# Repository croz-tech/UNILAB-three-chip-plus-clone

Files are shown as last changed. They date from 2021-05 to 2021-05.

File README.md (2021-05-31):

# UNILAB three-chip-plus-clone
**A clone of the main UNILAB 6502 learning board, part number 540.300**<BR><BR>
Features & changes over the [original UNILAB educational system](http://retro.hansotten.nl/6502-sbc/three-chips-plus/):
- Compatible with 6502/6522 or newer 65C02/65C22 fully static parts
- 1Mhz crystal replaced with oscillator module (more readily available)
- Internal/external clock selectable by jumper
- Address bus, Data bus, R/W and Clock available on headers to be compatible with [Ben Eater](https://eater.net/6502)'s [Arduino Mega Moitor](https://eater.net/downloads/6502-monitor.ino)
- Compatible with original three-chip-plus I/O peripheral boards, Program Memory Board, and Program Loader
- Original PCB form factor (yes, rather large by today's standards but I went for originality
- **See note at bottom of this page for ISS1 (ONLY ISS1) board error and modification**

## Assembled PCB (ISS1):


## Schematic (ISS2):


## ERROR and correction for ISS1 schematic and PCB
Note: there are two errors on the ISS1 **ONLY** schematic and boards, these are fixed on ISS2 in the design:
1) Polarity of POWER IN is reversed on the PCB legend (but correctly diode-protected)
2) Clock error, where U4 (the 6522 pin 25) should be driven with PHI2 (same phase as U5, the 6502) and U2 pins 2,10,12 should be driven with ~PHI2 (inverted phase compared to the 6502 and 6522).  Correcting this involves two track breaks and two wires being fitted to the PCB as below (one on the component-side below the socket of U3, one on the solder-side):
Modification 1
Modification 2

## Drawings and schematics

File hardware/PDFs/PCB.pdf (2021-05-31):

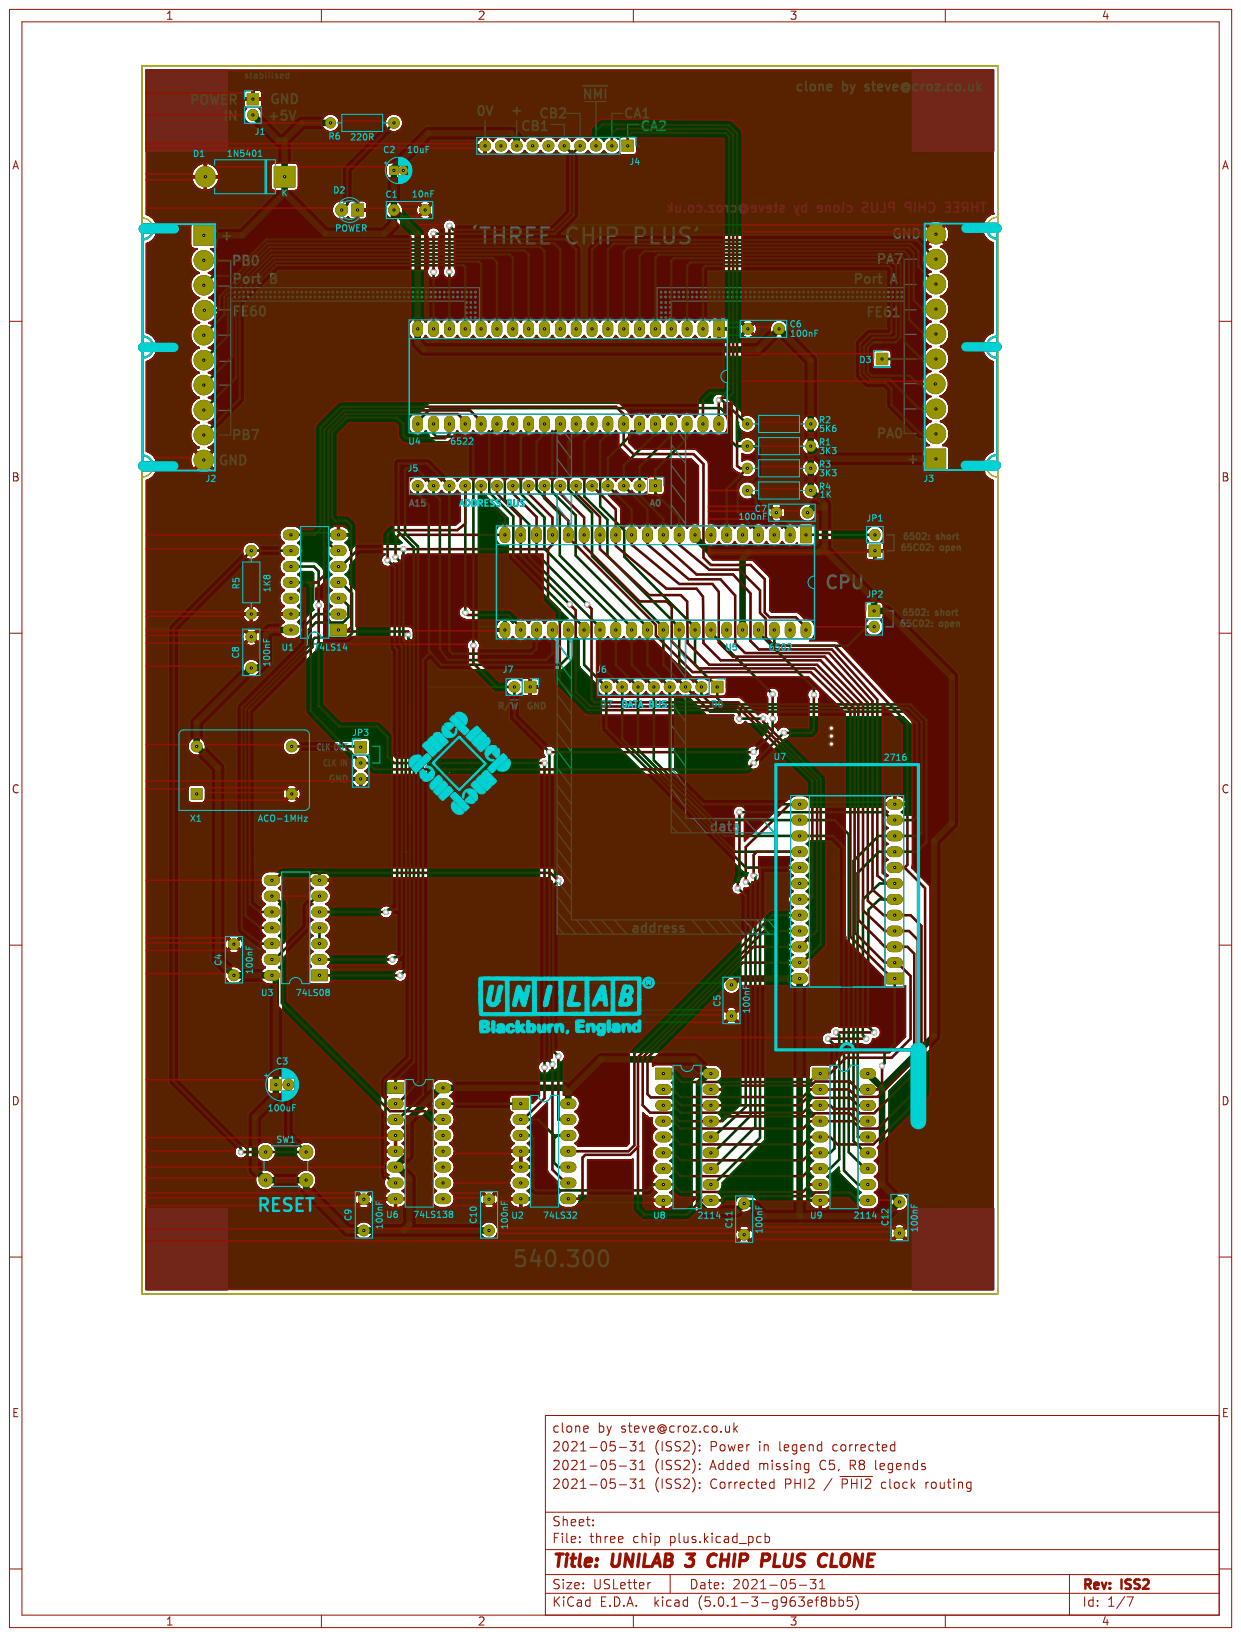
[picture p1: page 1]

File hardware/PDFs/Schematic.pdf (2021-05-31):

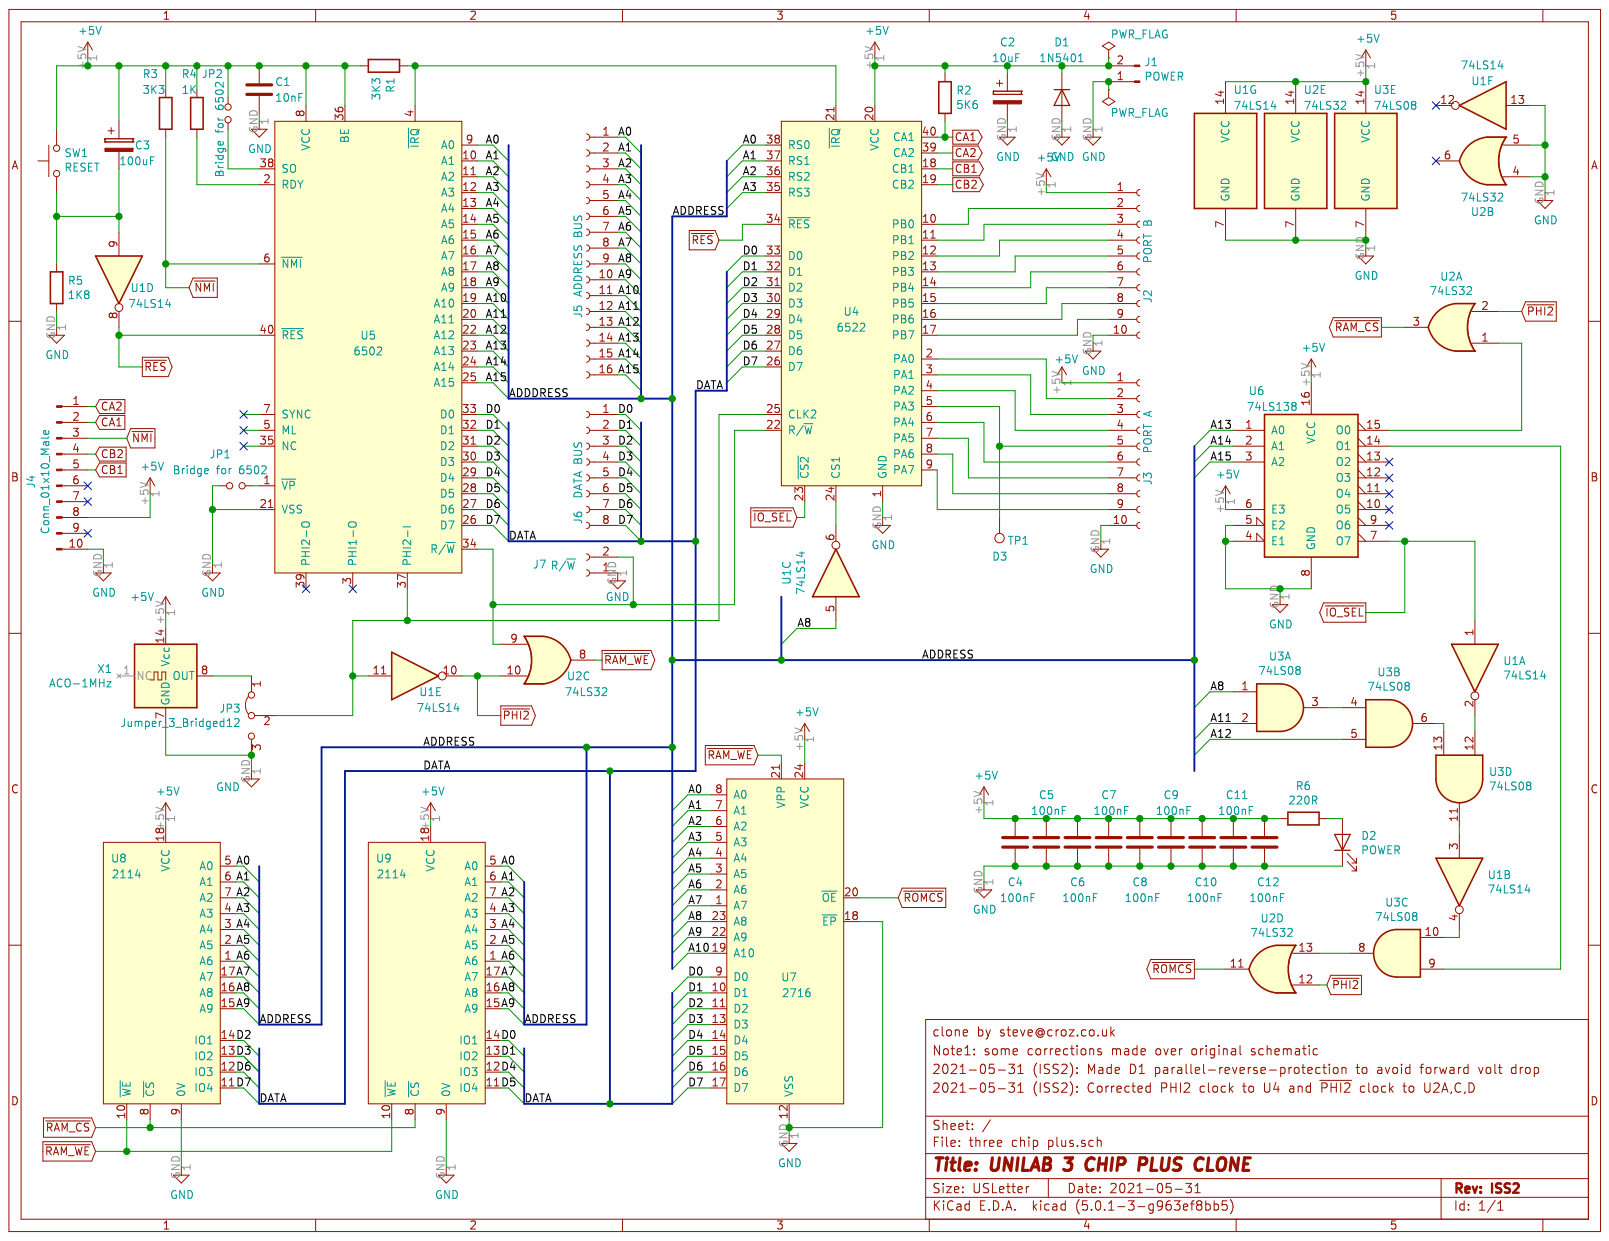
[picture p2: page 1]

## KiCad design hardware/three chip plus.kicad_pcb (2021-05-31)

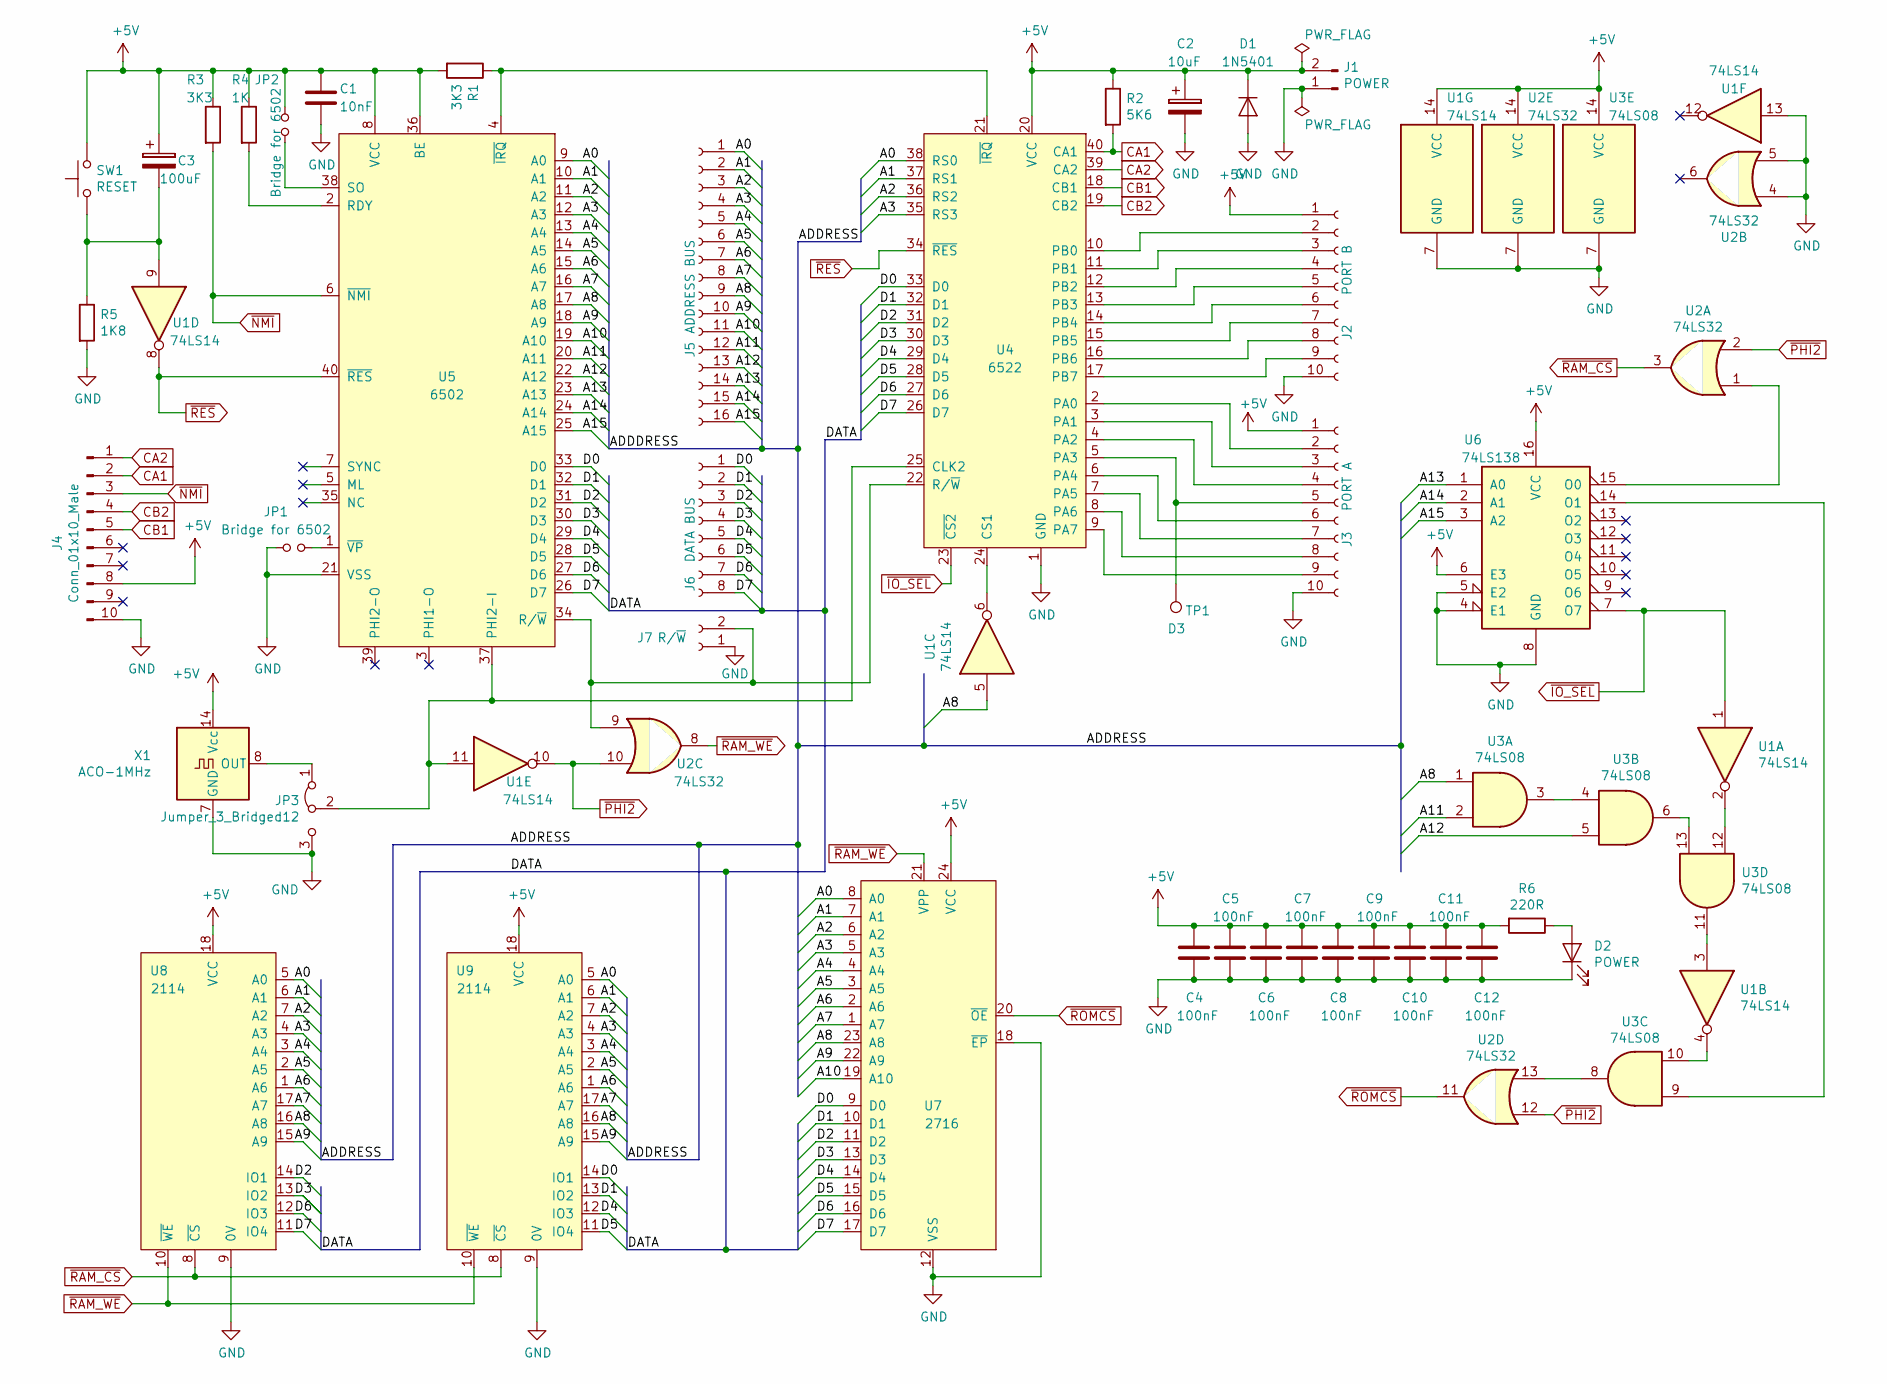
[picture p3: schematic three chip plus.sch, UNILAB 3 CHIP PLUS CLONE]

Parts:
C1: 10nF; C_Rect_L7.2mm_W2.5mm_P5.00mm_FKS2_FKP2_MKS2_MKP2
C2: 10uF; CP_Radial_D4.0mm_P1.50mm
C3: 100uF; CP_Radial_D5.0mm_P2.00mm
C4, C5, C6, C7, C8, C9, C10, C11, C12: 100nF; C_Rect_L7.2mm_W2.5mm_P5.00mm_FKS2_FKP2_MKS2_MKP2
D1: 1N5401; D_DO-201AD_P12.70mm_Horizontal
D2: POWER; LED_D3.0mm
J1: POWER; PinHeader_1x02_P2.54mm_Vertical
J2: PORT B; 10W_RA_Female
J3: PORT A; 10W_RA_Female
J4: Conn_01x10_Male; PinHeader_1x10_P2.54mm_Vertical
J5: ADDRESS BUS; PinHeader_1x16_P2.54mm_Vertical
J6: DATA BUS; PinHeader_1x08_P2.54mm_Vertical
J7: R/~W; PinHeader_1x02_P2.54mm_Vertical
JP1, JP2: Bridge for 6502; PinHeader_1x02_P2.54mm_Vertical
JP3: Jumper_3_Bridged12; PinHeader_1x03_P2.54mm_Vertical
R1, R3: 3K3; R_Axial_DIN0207_L6.3mm_D2.5mm_P10.16mm_Horizontal
R2: 5K6; R_Axial_DIN0207_L6.3mm_D2.5mm_P10.16mm_Horizontal
R4: 1K; R_Axial_DIN0207_L6.3mm_D2.5mm_P10.16mm_Horizontal
R5: 1K8; R_Axial_DIN0207_L6.3mm_D2.5mm_P10.16mm_Horizontal
R6: 220R; R_Axial_DIN0207_L6.3mm_D2.5mm_P10.16mm_Horizontal
SW1: RESET; SW_PUSH_6mm
TP1: D3; PinHeader_1x01_P2.54mm_Vertical
U1: 74LS14; DIP-14_W7.62mm_LongPads
U2: 74LS32; DIP-14_W7.62mm_LongPads
U3: 74LS08; DIP-14_W7.62mm_LongPads
U4: 6522; DIP-40_W15.24mm_Socket_LongPads
U5: 6502; DIP-40_W15.24mm_Socket_LongPads
U6: 74LS138; DIP-16_W7.62mm_LongPads
U7: 2716; DIP-24_W15.24mm_Socket_LongPads_ZIF
U8, U9: 2114; DIP-18_W7.62mm_LongPads
X1: ACO-1MHz; Oscillator_DIP-14

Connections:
+5V: C1.1, C2.1, C3.1, C4.1, C5.1, C6.1, C7.1, C8.1, C9.1, C10.1, C11.1, C12.1, D1.1 (K), J1.2, J2.1, J3.1, J4.8, JP2.1, R1.2, R2.1, R3.1, R4.1, R6.2, SW1.2, U1.14 (VCC), U2.14 (VCC), U3.14 (VCC), U4.20 (VCC), U5.8 (VCC), U5.36 (BE), U6.6 (E3), U6.16 (VCC), U7.24 (VCC), U8.18 (VCC), U9.18 (VCC), X1.14 (Vcc)
/A0: J5.1, U4.38 (RS0), U5.9 (A0), U7.8 (A0), U8.5 (A0), U9.5 (A0)
/A1: J5.2, U4.37 (RS1), U5.10 (A1), U7.7 (A1), U8.6 (A1), U9.6 (A1)
/A2: J5.3, U4.36 (RS2), U5.11 (A2), U7.6 (A2), U8.7 (A2), U9.7 (A2)
/A3: J5.4, U4.35 (RS3), U5.12 (A3), U7.5 (A3), U8.4 (A3), U9.4 (A3)
/A4: J5.5, U5.13 (A4), U7.4 (A4), U8.3 (A4), U9.3 (A4)
/A5: J5.6, U5.14 (A5), U7.3 (A5), U8.2 (A5), U9.2 (A5)
/A6: J5.7, U5.15 (A6), U7.2 (A6), U8.1 (A6), U9.1 (A6)
/A7: J5.8, U5.16 (A7), U7.1 (A7), U8.17 (A7), U9.17 (A7)
/A8: J5.9, U1.5, U3.1, U5.17 (A8), U7.23 (A8), U8.16 (A8), U9.16 (A8)
/A9: J5.10, U5.18 (A9), U7.22 (A9), U8.15 (A9), U9.15 (A9)
/A10: J5.11, U5.19 (A10), U7.19 (A10)
/A11: J5.12, U3.2, U5.20 (A11)
/A12: J5.13, U3.5, U5.22 (A12)
/A13: J5.14, U5.23 (A13), U6.1 (A0)
/A14: J5.15, U5.24 (A14), U6.2 (A1)
/A15: J5.16, U5.25 (A15), U6.3 (A2)
/D0: J6.1, U4.33 (D0), U5.33 (D0), U7.9 (D0), U9.14 (IO1)
/D1: J6.2, U4.32 (D1), U5.32 (D1), U7.10 (D1), U9.13 (IO2)
/D2: J6.3, U4.31 (D2), U5.31 (D2), U7.11 (D2), U8.14 (IO1)
/D3: J6.4, U4.30 (D3), U5.30 (D3), U7.13 (D3), U8.13 (IO2)
/D4: J6.5, U4.29 (D4), U5.29 (D4), U7.14 (D4), U9.12 (IO3)
/D5: J6.6, U4.28 (D5), U5.28 (D5), U7.15 (D5), U9.11 (IO4)
/D6: J6.7, U4.27 (D6), U5.27 (D6), U7.16 (D6), U8.12 (IO3)
/D7: J6.8, U4.26 (D7), U5.26 (D7), U7.17 (D7), U8.11 (IO4)
CA1: J4.2, R2.2, U4.40 (CA1)
CA2: J4.1, U4.39 (CA2)
CB1: J4.5, U4.18 (CB1)
CB2: J4.4, U4.19 (CB2)
GND: C1.2, C2.2, C4.2, C5.2, C6.2, C7.2, C8.2, C9.2, C10.2, C11.2, C12.2, D1.2 (A), D2.1 (K), J1.1, J2.10, J3.10, J4.10, J7.1, JP1.1, JP3.3 (B), R5.2, U1.7 (GND), U1.13, U2.4, U2.5, U2.7 (GND), U3.7 (GND), U4.1 (GND), U5.21 (VSS), U6.4 (E1), U6.5 (E2), U6.8 (GND), U7.12 (VSS), U7.18 (~EP), U8.9 (0V), U9.9 (0V), X1.7 (GND)
unnamed: C3.2, R5.1, SW1.1, U1.9
unnamed: D2.2 (A), R6.1
unnamed: J2.2, U4.10 (PB0)
unnamed: J2.3, U4.11 (PB1)
unnamed: J2.4, U4.12 (PB2)
unnamed: J2.5, U4.13 (PB3)
unnamed: J2.6, U4.14 (PB4)
unnamed: J2.7, U4.15 (PB5)
unnamed: J2.8, U4.16 (PB6)
unnamed: J2.9, U4.17 (PB7)
unnamed: J3.2, U4.2 (PA0)
unnamed: J3.3, U4.3 (PA1)
unnamed: J3.4, U4.4 (PA2)
unnamed: J3.5, TP1.1, U4.5 (PA3)
unnamed: J3.6, U4.6 (PA4)
unnamed: J3.7, U4.7 (PA5)
unnamed: J3.8, U4.8 (PA6)
unnamed: J3.9, U4.9 (PA7)
unnamed: J7.2, U2.9, U4.22 (R/~W), U5.34 (R/~W)
unnamed: JP1.2, U5.1 (~VP)
unnamed: JP2.2, U5.38 (SO)
unnamed: JP3.1 (A), X1.8 (OUT)
unnamed: JP3.2 (C), U1.11, U4.25 (CLK2), U5.37 (PHI2-I)
unnamed: R1.1, U4.21 (~IRQ), U5.4 (~IRQ)
unnamed: R4.2, U5.2 (RDY)
unnamed: U1.2, U3.12
unnamed: U1.3, U3.11
unnamed: U1.4, U3.10
unnamed: U1.6, U4.24 (CS1)
unnamed: U2.1, U6.15 (O0)
unnamed: U2.13, U3.8
unnamed: U3.3, U3.4
unnamed: U3.9, U6.14 (O1)
unnamed: U3.6, U3.13
~IO_SEL: U1.1, U4.23 (~CS2), U6.7 (O7)
~NMI: J4.3, R3.2, U5.6 (~NMI)
~PHI2: U1.10, U2.2, U2.10, U2.12
~RAM_CS: U2.3, U8.8 (~CS), U9.8 (~CS)
~RAM_WE: U2.8, U7.21 (VPP), U8.10 (~WE), U9.10 (~WE)
~RES: U1.8, U4.34 (~RES), U5.40 (~RES)
~ROMCS: U2.11, U7.20 (~OE)

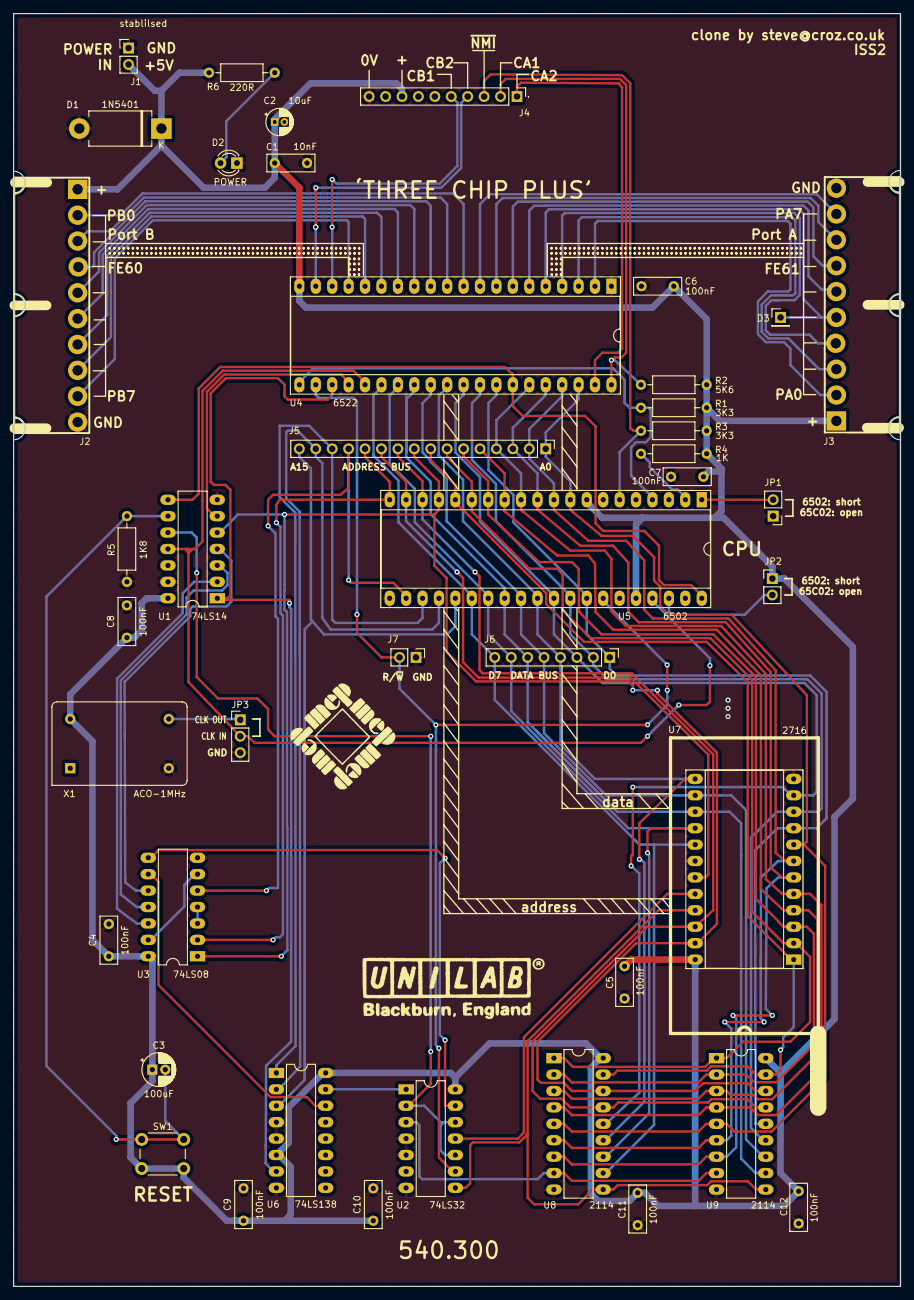
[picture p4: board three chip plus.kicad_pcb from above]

Board: 2 copper layers, 137.2 x 196.8 mm, 42 parts (0 on the bottom side), 71 nets.

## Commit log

2021-05-31 Initial revision
    Initial revision design: schematics, symbols, footprints and board
    [three chip plus-NPTH.drl, three chip plus-PTH.drl, three chip plus.gbl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]
2021-05-31 ISS2 Updates
    Change log:
    1. corrected error in PHI2/~PHI2~ clocks to U4 and U2 (schematic & PCB)
    2. made D1 parallel protection to avoid volt drop on +5V rail
    3. added missing R5, C2 legends (PCB)
    4. corrected Power In legend polarity (PCB)
    [three chip plus.kicad_pcb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]
2021-05-31 Update README.md
    Updated to show new schematic and that modifications necessary for ISS1 only
